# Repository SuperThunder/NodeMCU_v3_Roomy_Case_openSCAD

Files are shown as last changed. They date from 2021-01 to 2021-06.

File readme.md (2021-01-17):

## NodeMCU v3 Roomy Case with Ventilated Sensor Bay

A spacious case for the NodeMCU v3 made in openSCAD. Has enough room to hold the board, plug in dupont connectors, and route the connectors to a ventilated sensor bay (eg for temperature sensor). 

#### Note: Not a snug fit! The NodeMCU will likely fall off the supports without tape or the tension of the dupont connectors to hold it in place.

I made this case so that I could use NodeMCU v3 boards that I had as part of a wifi MQTT temperature reporting system without desoldering the DuPont connectors. Using DuPont connectors requires a few centimetres of clearance from the PCB, and the temperature sensors need to be a good distance away from the board to avoid being heated, so the case is quite bulky.

## Print instructions
- Print the main case without support
- Print the lid with supports (not strictly required but the snap fit triangles will droop a bit otherwise)
- I printed on an Ender 3 with PLA at 0.28mm 60mm/s 20% infill and found the results acceptable

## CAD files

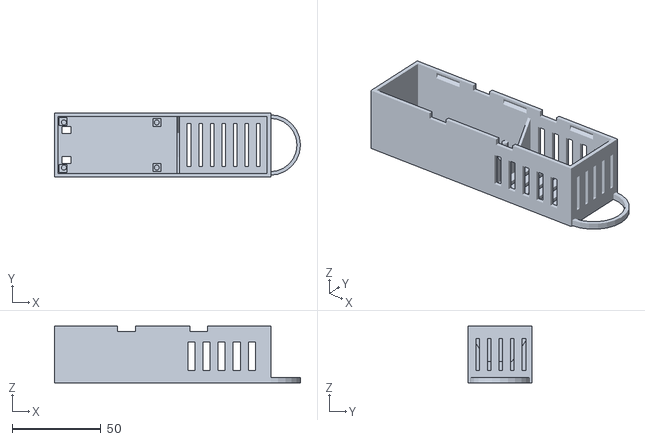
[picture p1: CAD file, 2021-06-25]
nodemcu_v3_roomy_sensor.stl
138.3 x 36.0 x 32.0

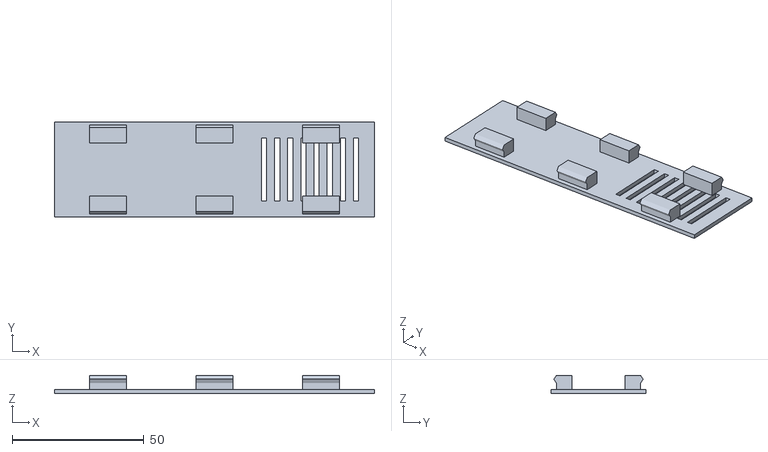
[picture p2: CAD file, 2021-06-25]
nodemcu_v3_roomy_lid.stl
121.6 x 36.0 x 7.00

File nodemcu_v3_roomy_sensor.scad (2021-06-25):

// Case for NodeMCU v3 with enough vertical space to use dupont cables, and long enough to reduce ESP heat getting to temperature sensor


// 57.8mm for the board, doubled for sensor space
inner_length_param = 57.8;

inner_width_param = 31.0;

inner_height = 30;

// 4mm to allow for RF shield and soldered headers. Used to hold up the board by the edges
floor_to_pcb_margin = 4;
pcb_wall_margin = 0.5; //margin from the wall to the PCB edge - does result in USB port being slightly recessed

bottom_thickness = 2.0;

wall_thickness = 2.0;

inner_wall_thickness = 1.6;
inner_wall_height = 10;

//Height with margin for cable
usb_height = 7.5;

//Width with margin for cable
usb_width = 12.5;


//Corner posts
corner_post_protrusion_height = 4;
//corner_post_outer_radius = 3;
corner_post_inner_radius = 1.4;
corner_post_pcb_radius = 1.5; //M3 hole?
//used for center of support/holding posts
//edge of protruding post from x wall
corner_post_x_from_wall = 1.3;
//edge of protruding post from y wall
corner_post_y_from_wall = 1.3;


//Snapfit hole values
//snapfit_hole_width = 12;
//snapfit_hole_thickness = 6;
//snapfit_hole_height = 3;
//snapfit_hole_offset = 4; //4mm from top

//Values for snap fit mechanism
triangle_mount_base = 3;
triangle_mount_length = 14;
triangle_mount_dist_from_top = 1;


//CALCULATED VALUES
//add margin so board is not pressed tight
inner_length = inner_length_param + pcb_wall_margin*2;
inner_width = inner_width_param + pcb_wall_margin*2;

//add wall thickness
inner_length_full = inner_length*2;
length_full = inner_length_full+wall_thickness*2;

width_full = inner_width+wall_thickness*2;

height_full = bottom_thickness+inner_height;

// overall case
translate([0, 0, 0]) union()
{
    //generate empty box with cutouts
    difference()
    {
        cube([length_full, width_full, height_full], 0);
        
        // main cutout
        translate([wall_thickness, wall_thickness, bottom_thickness]) cube([inner_length_full, inner_width, inner_height+1]);
        
        // USB cutout, placed in the center starting at floor height
        translate([-0.5, width_full/2 - usb_width/2, bottom_thickness]) cube([wall_thickness*3,  usb_width, usb_height+0.5]);
        
        //button holes
        generate_button_holes();
        
        //vent holes
        generate_rectangular_vent_holes();
        
        //inner snap fit holes
        translate([0,0,height_full-triangle_mount_dist_from_top-triangle_mount_base]) generate_snapfit_holes(3, triangle_mount_length);
    translate([0,width_full,height_full-triangle_mount_dist_from_top-triangle_mount_base]) mirror([0,1,0]) generate_snapfit_holes(3, triangle_mount_length);
        
        //holes for more easily removing the snapfit lid
        translate([length_full/6*2 - 5,0,height_full-3]) cube([10, wall_thickness*2,3]);    
        translate([length_full/6*2 - 5,width_full-wall_thickness,height_full-3]) cube([10, wall_thickness*2, 3]);
        translate([length_full/6*4 - 5,0,height_full-3]) cube([10, wall_thickness*2,3]);    
        translate([length_full/6*4 - 5,width_full-wall_thickness,height_full-3]) cube([10, wall_thickness*2, 3]);
        
        
    }
   
    
    //corner posts
    generate_posts();
    
    //wall seperating nodemcu and sensor areas
    generate_inner_wall();
    
    //hook
    translate([length_full-0.3, width_full/2, 0]) generate_hook();
    
}



//larger radius, smaller radius, transition height, total height
module retaining_cylinder(r, h)
{
    $fn = 50;
    //cylinder(trh, ro, ro, false); 
    //translate([-ro, -ro, 0]) cube([ro*2, ro*2, trh]);
    cylinder(h, r, r, false);
}

//square support ledge
module support_ledge()
{
    //doubled to get diameter, and then +50% to get a suitable overhang
    edge_length = 2*corner_post_pcb_radius*1.5;
    //echo("edge_length of support: ");
    //echo(edge_length);
    //translated so it is centered with the cylinder
    translate([-edge_length/2, -edge_length/2, 0]) cube([edge_length, edge_length, bottom_thickness+floor_to_pcb_margin]);
}

module corner_post()
{
   // support_post(corner_post_outer_radius, corner_post_inner_radius, bottom_thickness+floor_to_pcb_margin, bottom_thickness+floor_to_pcb_margin+5);
    retaining_cylinder(corner_post_inner_radius, bottom_thickness+floor_to_pcb_margin+corner_post_protrusion_height);
}

module generate_posts()
{   
 //offset from y axis and PCB hole to hole distance
 x_offset = wall_thickness + corner_post_x_from_wall + corner_post_pcb_radius + pcb_wall_margin;
 y_offset = corner_post_pcb_radius + wall_thickness + corner_post_y_from_wall + pcb_wall_margin;
 x_cross = inner_length - 2*corner_post_x_from_wall - 2*corner_post_pcb_radius - 2*pcb_wall_margin;
 y_cross = inner_width - 2*corner_post_y_from_wall - 2*corner_post_pcb_radius - 2*pcb_wall_margin;
    
    
//The bottom square supports are shifted to nestle them in the corner
//bottom right
 translate([x_offset, y_offset, 0]) union()
 {
    translate([-0.4, -0.5, 0]) support_ledge();
    corner_post();
 }
    
//bottom left
 translate([x_offset, y_offset+y_cross, 0]) union()
 {
    translate([-0.4, 0.5, 0]) support_ledge();
    corner_post();   
 }

//top right
 translate([x_offset + x_cross, y_offset, 0]) union()
 {
    support_ledge();
    corner_post();    
 }

//top left
 translate([x_offset + x_cross, y_offset + y_cross, 0]) union()
 {
    support_ledge();
    corner_post();      
 }

}

module generate_inner_wall()
{
   triangle_length = inner_width / 3;
   triangle_height = height_full - triangle_mount_dist_from_top - triangle_mount_base - inner_wall_height - bottom_thickness;
    
   translate([inner_length+10, wall_thickness, 0]) union()
   {   
    //lower rectangular portion 
    cube([inner_wall_thickness, inner_width+0.4, inner_wall_height+bottom_thickness]);
       
    //triangular support on left and  right
    //y axis wall
    translate([inner_wall_thickness, triangle_length, inner_wall_height]) rotate([0, 0, 180]) prism(inner_wall_thickness, triangle_length, triangle_height);
       
    //far y wall
    translate([0, inner_width-triangle_length, inner_wall_height]) rotate([0, 0, 0]) prism(inner_wall_thickness, triangle_length, triangle_height);
       
   }
}

//6 1cm holes, 3 on each side
//module generate_snapfit_holes()
//{
//    
//    hole_width = snapfit_hole_width;
//    hole_thickness = snapfit_hole_thickness;
//    hole_height = snapfit_hole_height;
//    hole_offset = snapfit_hole_offset;
//    
//    //put holes at 10, 45, 90%
//    hole_y_offset = -1*hole_thickness/2;
//    base_x_offset = wall_thickness + 0.10*inner_length_full;
//    
//    hole_z_offset = height_full - hole_height - hole_offset; //4mm from top
//    
//    //along y axis
//    gen_hole_line();
//    //along far y wall
//    translate([0, width_full, 0]) gen_hole_line();
//    
//    
//    module gen_hole_line()
//    {
//        translate([base_x_offset, hole_y_offset, hole_z_offset]) cube([hole_width, hole_thickness, hole_height]); 
//        translate([base_x_offset + inner_length_full*0.35, hole_y_offset, hole_z_offset]) cube([hole_width, hole_thickness, hole_height]);
//        translate([base_x_offset + inner_length_full*0.7, hole_y_offset, hole_z_offset]) cube([hole_width, hole_thickness, hole_height]);
//    }
//    
//}

module generate_button_holes()
{
    button_hole_x = 5;
    button_hole_y = 3.8;
    
    //distance from PCB edge to button along width
    button_distance_from_edge_y = 5.6;
    button_distance_from_edge_x = 2.2;
    
    //RST button
    //subtract half of cube width to center it
    translate([wall_thickness+button_distance_from_edge_x, wall_thickness + button_distance_from_edge_y, 0]) cube([button_hole_x, button_hole_y, bottom_thickness*1.5]);
    
    //Flash button
    translate([wall_thickness+button_distance_from_edge_x, width_full-wall_thickness-button_distance_from_edge_y - button_hole_y, 0]) cube([button_hole_x, button_hole_y, bottom_thickness*1.5]);
    
}
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

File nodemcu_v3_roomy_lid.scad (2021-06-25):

// 57.8mm for the board, doubled for sensor space
inner_length_param = 57.8;

inner_width_param = 31.0;

//inner_height = 3;


pcb_wall_margin = 0.5; //margin from the wall to the PCB edge - does result in USB port being slightly recessed


//Values used to get retaining posts to know where the board is and corner post protrusions are so we can avoid conflicting with them with our holding columns 
// 4mm to allow for RF shield and soldered headers. Used to hold up the board by the edges
floor_to_pcb_margin = 4;
case_inner_height = 30;
nodemcu_v3_pcb_thickness = 1.6;
corner_post_protrusion_height = 4;
corner_post_inner_radius = 1.4;
corner_post_pcb_radius = 1.5; //M3 hole?
//edge of protruding post from x wall
corner_post_x_from_wall = 1.3;
//edge of protruding post from y wall
corner_post_y_from_wall = 1.3;


bottom_thickness = 1.6;

wall_thickness = 2;

//snap_offset_from_top_nominal = 4;
//snap_offset_droop_margin = 0.1; //the snapfit triangles tend to sag, when printing, so make the post a little taller to account for this


//Values for snap fit mechanism
triangle_mount_base = 3;
triangle_mount_length = 14;
triangle_mount_dist_from_top = 1;


//CALCULATED VALUES
//add margin so board is not pressed tight
inner_length = inner_length_param + pcb_wall_margin*2;
inner_width = inner_width_param + pcb_wall_margin*2;

//TODO use above values if printed case has PCB wall margin
//inner_length = inner_length_param;
//inner_width = inner_width_param;

//add wall thickness
inner_length_full = inner_length*2;
length_full = inner_length_full+wall_thickness*2;

width_full = inner_width+wall_thickness*2;

//height_full = bottom_thickness+inner_height;

//account for potential droop
//snap_offset_from_top = snap_offset_from_top_nominal + snap_offset_droop_margin;


module generate_snapfit_solids(count, length)
{
    interval = length_full / 2 / count;
    
    //left side
    for(i = [0:count-1])
    {
        translate([2*i*interval + interval, width_full/2, 0]) snapfit_solid();
    }
    
    module snapfit_solid()
    {
        //the total height of the mount
        total_mount_height = triangle_mount_dist_from_top+triangle_mount_base;
        
        translate([0,-width_full/2+wall_thickness+triangle_mount_base, total_mount_height/2]) cube([length, triangle_mount_base*2, total_mount_height], center=true);
        translate([0,-width_full/2+wall_thickness, triangle_mount_dist_from_top]) triangle_mount(triangle_mount_base, wall_thickness/2, length);
    }
    
}

//lid with clips
//meant to be 6mm, but ended up as 3.8mm
translate([0, 0, 0]) union()
{
    
    
    //generate empty box with cutouts
    difference()
    {
        //cube([length_full, width_full, height_full], 0);
        
        //flat plate
        cube([length_full, width_full, bottom_thickness], 0);
        
        // main cutout
        //translate([wall_thickness, wall_thickness, bottom_thickness]) cube([inner_length_full, inner_width, inner_height+1]);
        
        //vent holes
        generate_vent_holes();
    }
    
    translate([0,0,bottom_thickness]) generate_snapfit_solids(3, triangle_mount_length);
    translate([0,width_full,bottom_thickness]) mirror([0,1,0]) generate_snapfit_solids(3, triangle_mount_length);
    
    
            //translate([length_full/4,-width_full/2+triangle_mount_base*2, triangle_mount_dist_from_top/2+bottom_thickness/2+triangle_mount_base/2]) cube([triangle_mount_length, triangle_mount_base*2, triangle_mount_dist_from_top+triangle_mount_base], center=true);
        //translate([length_full/4,-width_full/2+triangle_mount_base, triangle_mount_dist_from_top+bottom_thickness/2]) triangle_mount(triangle_mount_base, wall_thickness/2, triangle_mount_length);
            
        //bottom right triangle mount
//        translate([-ir_case_length/4,-ir_case_full_width/2+triangle_mount_base*2, triangle_mount_dist_from_top/2+lid_thickness/2+triangle_mount_base/2]) cube([triangle_mount_length, triangle_mount_base*2, triangle_mount_dist_from_top+triangle_mount_base], center=true);
//        translate([-ir_case_length/4,-ir_case_full_width/2+triangle_mount_base,triangle_mount_dist_from_top+lid_thickness/2]) triangle_mount(triangle_mount_base, wall_thickness/2, triangle_mount_length);
//            
//        //top left triangle mount
//        translate([ir_case_length/4,ir_case_full_width/2-triangle_mount_base*2, triangle_mount_dist_from_top/2+lid_thickness/2+triangle_mount_base/2]) cube([triangle_mount_length, triangle_mount_base*2, triangle_mount_dist_from_top+triangle_mount_base], center=true);
//        translate([ir_case_length/4,ir_case_full_width/2-triangle_mount_base,triangle_mount_dist_from_top+lid_thickness/2]) mirror([0,1,0]) triangle_mount(triangle_mount_base, wall_thickness/2, triangle_mount_length);
//            
//        //bottom left triangle mount
//        translate([-ir_case_length/4,ir_case_full_width/2-triangle_mount_base*2, triangle_mount_dist_from_top/2+lid_thickness/2+triangle_mount_base/2]) cube([triangle_mount_length, triangle_mount_base*2, triangle_mount_dist_from_top+triangle_mount_base], center=true);
//        translate([-ir_case_length/4,ir_case_full_width/2-triangle_mount_base,triangle_mount_dist_from_top+lid_thickness/2]) mirror([0,1,0]) triangle_mount(triangle_mount_base, wall_thickness/2, triangle_mount_length);
    //}
    
    //snapfit clips
    //generate_snapfit_clips();
    
    //holding posts/columns to hold board in place
    //too fragile, snap off and make it hard to put the lid on
    //generate_holding_posts();
    
    //TODO: make 2-3 'walls' sticking up from the lid to prevent the top of the sensor walls from being squeezed inwards and causing layer separation about the PCB
    //the walls could then potentially taper inwards to hold in the board
    
}


module generate_vent_holes()
{
    //top of sensor bay
    translate([length_full - total_vent_line_length(8, 2, 3) - 6, (width_full-24)/2, bottom_thickness+1]) rotate([-90,0,0]) generate_vent_line(8, 24, 2, 5, 3);
    
    
    module generate_vent_line(count, height, width, thickness, spacing)
    {
        function xpos(n,wi,sp) = n*wi + n*sp;
        
        //generate the specified size holes at the given spacing
        for(i = [0:1:count-1])
        {            
            //echo("xpos:");
            //echo(xpos(i,width,spacing));
            translate([xpos(i,width,spacing), 0, 0]) gen_hole();  
        }
        
        module gen_hole()
        {
            cube([width, thickness, height]);
        }
    }
    
    //calculate total length from the left of the first vent hole to the right of the last
    function total_vent_line_length(count, width, spacing) = 
       count*(width+spacing) - spacing;
    
}

//from https://en.wikibooks.org/wiki/OpenSCAD_User_Manual/Primitive_Solids#polyhedron
module prism(l, w, h){
   polyhedron(
           points=[[0,0,0], [l,0,0], [l,w,0], [0,w,0], [0,w,h], [l,w,h]],
           faces=[[0,1,2,3],[5,4,3,2],[0,4,5,1],[0,3,4],[5,2,1]]
           );
  
   }
   
//from https://en.wikibooks.org/wiki/OpenSCAD_User_Manual/Primitive_Solids#polyhedron
//makes 3D triangles
module prism_isos(l, w, h){
   polyhedron(
           points=[[0,0,0], [l,0,0], [l,w,0], [0,w,0], [0,w/2,h], [l,w/2,h]],
           faces=[[0,1,2,3],[5,4,3,2],[0,4,5,1],[0,3,4],[5,2,1]]
           );
  
}

module triangle_mount(base, height, length)
{
    translate([-length/2,0,base/2]) rotate([90,0,0]) union(){
        //triangle portion
        //rotate([90,0,-90]) 
        translate([0,-base/2,0]) prism_isos(length,base,height);
        
        //rectangular support
        //rotate([0,90,0])
        //translate([-length/2,0,base]) 
        translate([length/2,0,-base/2]) cube([length,base,base], center=true);
    }
}

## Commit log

2021-01-17 add stl and readme
    [nodemcu_v3_roomy_lid.stl, nodemcu_v3_roomy_sensor.stl]
2021-01-17 print instructions
2021-01-21 tried adding retaining posts but it's too fragile - a single larger post in the center would probably work better
    [nodemcu_v3_roomy_lid.scad, nodemcu_v3_roomy_lid.stl, nodemcu_v3_roomy_sensor.scad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]
2021-01-21 some ideas on preventing squeeze and holding the pcb in
    [nodemcu_v3_roomy_lid.scad]
2021-06-25 update to internal snapfit design
    [nodemcu_v3_roomy_lid.scad, nodemcu_v3_roomy_lid.stl, nodemcu_v3_roomy_sensor.scad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]
